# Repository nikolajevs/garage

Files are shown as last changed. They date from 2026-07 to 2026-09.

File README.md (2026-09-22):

# 🚨 Garage Alarm System — ESP32 + LD2410C + RC522

Умная охранная сигнализация для гаража на базе ESP32.

## Возможности

- Детекция присутствия человека с помощью радара **LD2410C** (mmWave)
- Управление через RFID-считыватель **RC522** (SPI)
- Задержки на выход (30 сек) и вход (15 сек)
- Фильтр ложных срабатываний: тревога, только если присутствие держится не меньше 1 сек
- Автоматическое отключение сирены через 3 минуты (LED продолжает мигать, пока охрану не снимут картой)
- **Динамическое добавление карт через мастер-карту** — не нужно перепрошивать, чтобы добавить новую карту
- Все карты и мастер-карта хранятся в NVS (переживают перезагрузку и перепрошивку)
- Состояние охраны тоже хранится в NVS — отключение питания не снимает охрану
- Контроль радара: если при охране от LD2410 нет данных дольше 3 сек (обрыв/саботаж), запускается тревога
- Автоматическая переинициализация RC522, если он завис или сбросился от помех

## Пины подключения

| Компонент | Пин ESP32 |
|---|---|
| LD2410C TX | GPIO16 (RX2)  |
| LD2410C RX | GPIO17 (TX2)  |
| RC522 SDA (SS)  | GPIO5 |
| RC522 RST | GPIO4 |
| RC522 SCK | GPIO18 |
| RC522 MOSI | GPIO23 |
| RC522 MISO | GPIO19 |
| RC522 3.3V | 3.3V (⚠️ не 5V!) |
| Сирена/Реле | GPIO32 |
| LED индикатор | GPIO2 |

⚠️ RC522 питается строго от 3.3V — модуль обычно не имеет своего стабилизатора и не 5V-толерантен.
Сирену пришлось перенести с GPIO18 на GPIO32, так как GPIO18 занят аппаратным SPI (SCK) для RC522.

## Как работает

- **DISARMED** — Охрана выключена
- **EXIT_DELAY** — 30 сек на выход (медленное мигание LED)
- **ARMED** — Охрана активна (LED горит)
- **ENTRY_DELAY** — 15 сек на отключение (быстрое мигание)
- **ALARM** — Тревога! Сирена орёт

## Настройка

1. Загрузите прошивку и откройте Serial Monitor (115200 baud).
2. При первом запуске мастер-карта ещё не назначена — поднесите **любую** карту к RC522, она автоматически станет мастер-картой и сохранится в NVS.
3. Чтобы добавить обычную карту: поднесите **мастер-карту** (система должна быть снята с охраны, DISARMED) — LED начнёт часто мигать, это значит включён режим добавления. В течение 15 секунд поднесите новую карту — она сохранится в список разрешённых.
4. Повторное поднесение мастер-карты выключает режим добавления вручную (иначе он сам выключится через 15 сек).
5. Откалибруйте LD2410C через приложение HLKRadarTool.

### Serial-команды

| Команда | Действие |
|---|---|
| `list` | Показать мастер-карту и список обычных карт |
| `clear` | Удалить все обычные карты (мастер-карта не трогается) |
| `resetmaster` | Сбросить мастер-карту — следующая поднесённая карта станет новой мастер-картой |

## Библиотеки

- [MyLD2410](https://github.com/iavorvel/MyLD2410)
- [MFRC522](https://github.com/miguelbalboa/rfid)

**Проект готов к использованию!**

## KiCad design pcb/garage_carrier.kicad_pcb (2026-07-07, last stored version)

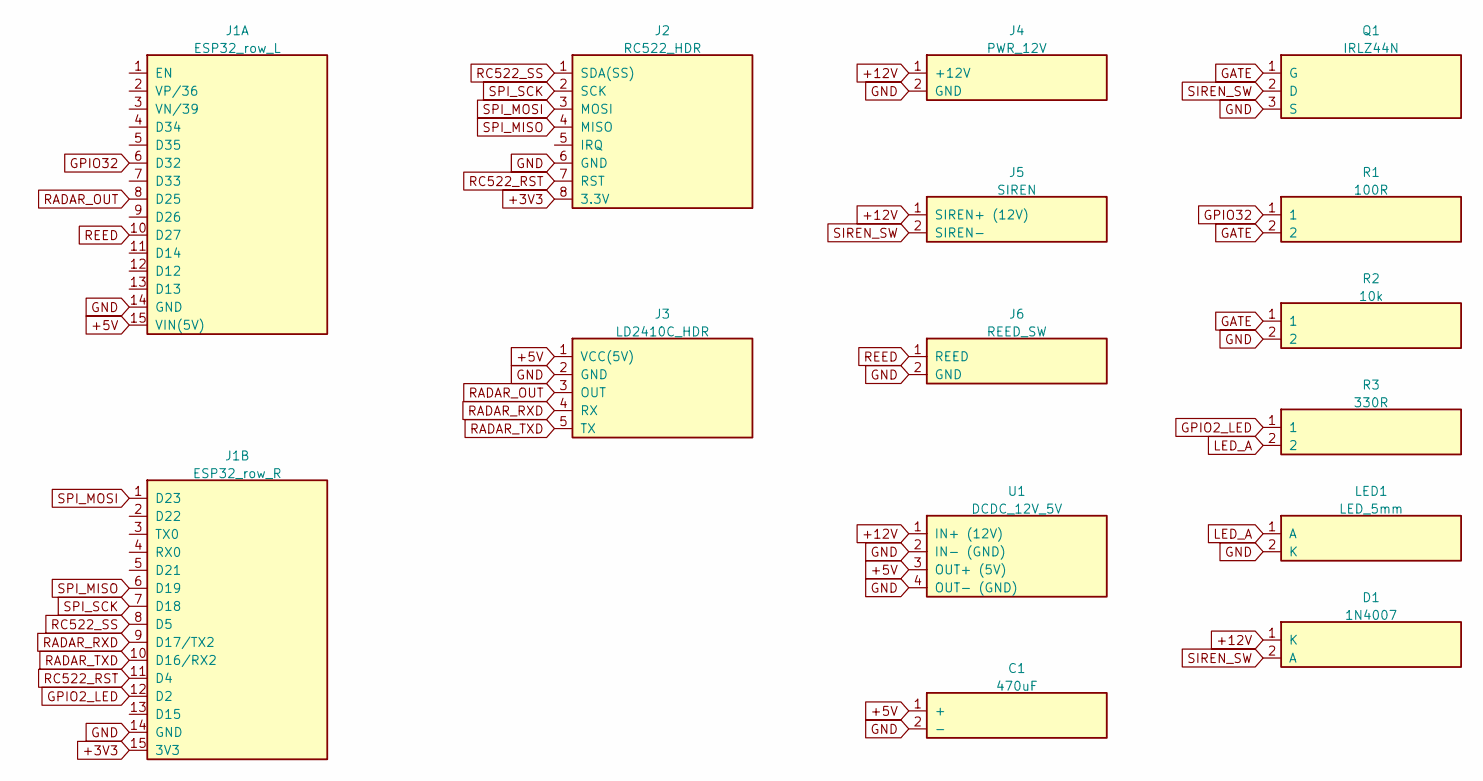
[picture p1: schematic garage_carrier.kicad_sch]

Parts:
C1: 470uF; C1
D1: 1N4007; D1
J1A: ESP32_row_L; J1A
J1B: ESP32_row_R; J1B
J2: RC522_HDR; J2
J3: LD2410C_HDR; J3
J4: PWR_12V; J4
J5: SIREN; J5
J6: REED_SW; J6
LED1: LED_5mm; LED1
Q1: IRLZ44N; Q1
R1: 100R; R1
R2: 10k; R2
R3: 330R; R3
U1: DCDC_12V_5V; U1

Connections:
+3V3: J1B.15 (3V3), J2.8 (3.3V)
+5V: C1.1 (+), J1A.15 (VIN(5V)), J3.1 (VCC(5V)), U1.3 (OUT+ (5V))
+12V: D1.1 (K), J4.1 (+12V), J5.1 (SIREN+ (12V)), U1.1 (IN+ (12V))
GATE: Q1.1 (G), R1.2, R2.1
GND: C1.2 (-), J1A.14 (GND), J1B.14 (GND), J2.6 (GND), J3.2 (GND), J4.2 (GND), J6.2 (GND), LED1.2 (K), Q1.3 (S), R2.2, U1.2 (IN- (GND)), U1.4 (OUT- (GND))
GPIO2_LED: J1B.12 (D2), R3.1
GPIO32: J1A.6 (D32), R1.1
LED_A: LED1.1 (A), R3.2
RADAR_OUT: J1A.8 (D25), J3.3 (OUT)
RADAR_RXD: J1B.9 (D17/TX2), J3.4 (RX)
RADAR_TXD: J1B.10 (D16/RX2), J3.5 (TX)
RC522_RST: J1B.11 (D4), J2.7 (RST)
RC522_SS: J1B.8 (D5), J2.1 (SDA(SS))
REED: J1A.10 (D27), J6.1 (REED)
SIREN_SW: D1.2 (A), J5.2 (SIREN-), Q1.2 (D)
SPI_MISO: J1B.6 (D19), J2.4 (MISO)
SPI_MOSI: J1B.1 (D23), J2.3 (MOSI)
SPI_SCK: J1B.7 (D18), J2.2 (SCK)

Board: 2 copper layers, 19 parts (0 on the bottom side), 18 nets, no tracks yet.

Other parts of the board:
H1: M3; H1
H2: M3; H2
H3: M3; H3
H4: M3; H4

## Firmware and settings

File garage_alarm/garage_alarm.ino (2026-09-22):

#include <Arduino.h>
#include <MyLD2410.h>
#include <SPI.h>
#include <MFRC522.h>
#include <Preferences.h>

// ================= ПИНЫ =================
#define LD2410_RX 16
#define LD2410_TX 17
#define RC522_SS   5
#define RC522_RST  4
// SPI (SCK/MOSI/MISO) - аппаратные пины ESP32: GPIO18/23/19
#define SIREN_PIN 32   // сирену перенесли с GPIO18, т.к. он занят под аппаратный SPI (SCK)
#define LED_PIN   2

// ================= НАСТРОЙКИ =================
const unsigned long EXIT_DELAY_MS   = 30000;
const unsigned long ENTRY_DELAY_MS  = 15000;
const unsigned long ALARM_TIMEOUT   = 180000;
const unsigned long MOTION_HOLD_MS  = 1000;
const unsigned long RFID_DEBOUNCE_MS = 600;
const unsigned long ADD_MODE_TIMEOUT_MS = 15000; // время на поднесение новой карты после мастер-карты
const unsigned long RADAR_TIMEOUT_MS = 3000;     // нет кадров от LD2410 дольше этого при охране = обрыв/саботаж
const unsigned long RC522_CHECK_MS   = 5000;     // период проверки, что RC522 жив
const int MAX_CARDS = 20;

// ================= СОСТОЯНИЯ =================
enum State { DISARMED, EXIT_DELAY, ARMED, ENTRY_DELAY, ALARM };
State state = DISARMED;
unsigned long stateTimer = 0;
unsigned long lastRFIDReadTime = 0;
unsigned long lastRC522Check = 0;

bool presence = false;             // по последнему кадру радара кто-то есть
unsigned long presenceSince = 0;   // когда присутствие началось
unsigned long lastRadarFrame = 0;  // когда пришёл последний кадр с данными

bool addModeActive = false;
unsigned long addModeStartedAt = 0;

// ================= УСТРОЙСТВА =================
MyLD2410 radar(Serial2);
MFRC522 rfid(RC522_SS, RC522_RST);
Preferences prefs;

// ================= ХРАНЕНИЕ КАРТ (NVS) =================
String masterUID = "";               // пусто = мастер-карта ещё не назначена
String storedCards[MAX_CARDS];
int storedCardCount = 0;
bool armedInNVS = false;             // была ли система на охране перед перезагрузкой

void loadFromNVS() {
  prefs.begin("garage", true);
  masterUID = prefs.getString("master", "");
  armedInNVS = prefs.getBool("armed", false);
  storedCardCount = prefs.getInt("count", 0);
  if (storedCardCount > MAX_CARDS) storedCardCount = MAX_CARDS;
  for (int i = 0; i < storedCardCount; i++) {
    storedCards[i] = prefs.getString(("card" + String(i)).c_str(), "");
  }
  prefs.end();
}

void saveMaster() {
  prefs.begin("garage", false);
  prefs.putString("master", masterUID);
  prefs.end();
}

void saveArmed(bool armed) {
  prefs.begin("garage", false);
  prefs.putBool("armed", armed);
  prefs.end();
}

void saveCards() {
  prefs.begin("garage", false);
  prefs.putInt("count", storedCardCount);
  for (int i = 0; i < storedCardCount; i++) {
    prefs.putString(("card" + String(i)).c_str(), storedCards[i]);
  }
  prefs.end();
}

bool isKnownCard(const String &uid) {
  for (int i = 0; i < storedCardCount; i++) {
    if (storedCards[i] == uid) return true;
  }
  return false;
}

bool addCard(const String &uid) {
  if (isKnownCard(uid)) return false;
  if (storedCardCount >= MAX_CARDS) return false;
  storedCards[storedCardCount++] = uid;
  saveCards();
  return true;
}

// ================= HELPERS =================
String uidToString(byte* uid, byte len) {
  String s = "";
  for (byte i = 0; i < len; i++) {
    if (uid[i] < 0x10) s += "0";
    s += String(uid[i], HEX);
  }
  s.toUpperCase();
  return s;
}

void blink(int times, int onMs, int offMs) {
  for (int i = 0; i < times; i++) {
    digitalWrite(LED_PIN, HIGH);
    delay(onMs);
    digitalWrite(LED_PIN, LOW);
    if (i < times - 1) delay(offMs);
  }
}

void sirenBeep(int ms) {
  digitalWrite(SIREN_PIN, HIGH);
  delay(ms);
  digitalWrite(SIREN_PIN, LOW);
}

void setState(State s) {
  bool wasArmed = (state != DISARMED);
  state = s;
  stateTimer = millis();
  Serial.printf("State -> %d\n", s);
  // запоминаем факт охраны в NVS, чтобы отключение питания не снимало охрану
  if ((s != DISARMED) != wasArmed) saveArmed(s != DISARMED);
  if (s == DISARMED) {
    digitalWrite(SIREN_PIN, LOW);
    digitalWrite(LED_PIN, LOW);
  }
}

// ================= SETUP =================
void setup() {
  Serial.begin(115200);
  Serial.setTimeout(50); // readStringUntil не будет висеть 1 сек, если в мониторе "No line ending"
  pinMode(SIREN_PIN, OUTPUT);
  pinMode(LED_PIN, OUTPUT);
  digitalWrite(SIREN_PIN, LOW);
  digitalWrite(LED_PIN, LOW);

  Serial2.setRxBufferSize(1024); // запас на время блокирующих blink()/sirenBeep()
  Serial2.begin(256000, SERIAL_8N1, LD2410_RX, LD2410_TX);
  if (!radar.begin()) {
    Serial.println("LD2410 не отвечает! Проверьте подключение.");
  }
  lastRadarFrame = millis();

  SPI.begin(); // SCK=18, MISO=19, MOSI=23 по умолчанию на ESP32
  rfid.PCD_Init();

  // не блокируем всю систему: радар и сирена работают, RC522 будет переинициализироваться в loop()
  byte version = rfid.PCD_ReadRegister(rfid.VersionReg);
  if (version == 0x00 || version == 0xFF) {
    Serial.println("RC522 not found! Повторная инициализация каждые 5 сек.");
  } else {
    Serial.print("RC522 OK, version 0x");
    Serial.println(version, HEX);
  }

  loadFromNVS();

  if (masterUID == "") {
    Serial.println("Мастер-карта не назначена! Поднесите любую карту к RC522 - она станет мастер-картой.");
  } else {
    Serial.println("Мастер-карта: " + masterUID);
  }
  Serial.println("Обычных карт в списке: " + String(storedCardCount));
  Serial.println("Serial-команды: list, clear, resetmaster");

  if (armedInNVS) {
    Serial.println("Перезагрузка во время охраны - снова на охране.");
    setState(ARMED);
  }
  Serial.println("Garage Alarm READY");
}

// ================= RC522 =================
// RC522 может зависнуть или сброситься от помех (например, от реле сирены):
// после сброса его регистры возвращаются к умолчанию и антенна выключена.
void checkRC522() {
  if (millis() - lastRC522Check < RC522_CHECK_MS) return;
  lastRC522Check = millis();

  byte version = rfid.PCD_ReadRegister(rfid.VersionReg);
  bool antennaOn = (rfid.PCD_ReadRegister(rfid.TxControlReg) & 0x03) == 0x03;
  if (version == 0x00 || version == 0xFF || !antennaOn) {
    Serial.println("RC522 не отвечает, переинициализация...");
    rfid.PCD_Init();
  }
}

// ================= RFID =================
void checkRFID() {
  if (millis() - lastRFIDReadTime < RFID_DEBOUNCE_MS) return;
  if (!rfid.PICC_IsNewCardPresent()) return;
  if (!rfid.PICC_ReadCardSerial()) return;

  String tag = uidToString(rfid.uid.uidByte, rfid.uid.size);
  lastRFIDReadTime = millis();
  Serial.println("TAG: " + tag);

  // --- Назначение мастер-карты при первом использовании ---
  if (masterUID == "") {
    if (isKnownCard(tag)) {
      // иначе обычная карта станет мастер-картой и перестанет ставить/снимать охрану
      Serial.println("Эта карта уже в списке обычных - поднесите другую (или сначала clear).");
      blink(2, 400, 200);
      rfid.PICC_HaltA();
      rfid.PCD_StopCrypto1();
      return;
    }
    masterUID = tag;
    saveMaster();
    Serial.println("Мастер-карта назначена: " + tag);
    blink(5, 100, 100);
    rfid.PICC_HaltA();
    rfid.PCD_StopCrypto1();
    return;
  }

  // --- Поднесли мастер-карту: переключаем режим добавления ---
  if (tag == masterUID) {
    if (state != DISARMED) {
      Serial.println("Режим добавления карт доступен только при снятой охране.");
      blink(2, 400, 200);
      rfid.PICC_HaltA();
      rfid.PCD_StopCrypto1();
      return;
    }
    addModeActive = !addModeActive;
    if (addModeActive) {
      addModeStartedAt = millis();
      Serial.println("Режим добавления ВКЛЮЧЁН. Поднесите новую карту в течение 15 сек.");
      blink(3, 150, 150);
    } else {
      Serial.println("Режим добавления выключен.");
      blink(1, 500, 0);
    }
    rfid.PICC_HaltA();
    rfid.PCD_StopCrypto1();
    return;
  }

  // --- Режим добавления активен: сохраняем новую карту ---
  if (addModeActive) {
    addModeActive = false;
    if (addCard(tag)) {
      Serial.println("Карта добавлена: " + tag);
      blink(3, 100, 100);
    } else {
      Serial.println("Карта уже есть в списке или лимит карт исчерпан: " + tag);
      blink(5, 80, 80);
    }
    rfid.PICC_HaltA();
    rfid.PCD_StopCrypto1();
    return;
  }

  // --- Обычная карта: ставим/снимаем с охраны ---
  if (isKnownCard(tag)) {
    if (state == DISARMED) {
      setState(EXIT_DELAY);
    } else {
      setState(DISARMED);
    }
    sirenBeep(150);
  } else {
    Serial.println("Access DENIED: " + tag);
    blink(1, 600, 0);
  }

  rfid.PICC_HaltA();
  rfid.PCD_StopCrypto1();
}

// ================= SERIAL КОМАНДЫ =================
void checkSerialCommands() {
  if (!Serial.available()) return;
  String cmd = Serial.readStringUntil('\n');
  cmd.trim();
  cmd.toLowerCase();

  if (cmd == "list") {
    Serial.println("Мастер-карта: " + (masterUID == "" ? "не назначена" : masterUID));
    Serial.println("Обычные карты (" + String(storedCardCount) + "):");
    for (int i = 0; i < storedCardCount; i++) {
      Serial.println("  " + storedCards[i]);
    }
  } else if (cmd == "clear") {
    storedCardCount = 0;
    saveCards();
    Serial.println("Список обычных карт очищен (мастер-карта сохранена).");
  } else if (cmd == "resetmaster") {
    masterUID = "";
    saveMaster();
    Serial.println("Мастер-карта сброшена. Поднесите новую карту, чтобы назначить её мастер-картой.");
  } else if (cmd.length() > 0) {
    Serial.println("Команды: list, clear, resetmaster");
  }
}

// ================= LOOP =================
void loop() {
  checkSerialCommands();
  checkRC522();
  checkRFID();

  // автоматический выход из режима добавления по таймауту
  if (addModeActive && millis() - addModeStartedAt > ADD_MODE_TIMEOUT_MS) {
    addModeActive = false;
    Serial.println("Время на добавление карты истекло, режим добавления выключен.");
  }

  // вычитываем все накопившиеся кадры радара
  MyLD2410::Response r;
  while ((r = radar.check()) != MyLD2410::FAIL) {
    if (r != MyLD2410::DATA) continue;
    lastRadarFrame = millis();
    bool p = radar.presenceDetected(); // движущаяся или неподвижная цель
    if (p && !presence) presenceSince = millis();
    presence = p;
  }

  unsigned long now = millis();

  // индикация режима добавления имеет приоритет над обычной индикацией LED
  if (addModeActive) {
    digitalWrite(LED_PIN, (now / 200) % 2);
  } else {
    switch (state) {
      case DISARMED:
        digitalWrite(LED_PIN, LOW);
        break;
      case EXIT_DELAY:
        digitalWrite(LED_PIN, (now / 300) % 2);
        if (now - stateTimer > EXIT_DELAY_MS) setState(ARMED);
        break;
      case ARMED:
        digitalWrite(LED_PIN, HIGH);
        // тревога, только если присутствие держится не меньше MOTION_HOLD_MS
        if (presence && now - presenceSince >= MOTION_HOLD_MS) {
          setState(ENTRY_DELAY);
        } else if (now - lastRadarFrame > RADAR_TIMEOUT_MS) {
          Serial.println("Нет данных от LD2410 - обрыв или саботаж!");
          setState(ENTRY_DELAY);
        }
        break;
      case ENTRY_DELAY:
        digitalWrite(LED_PIN, (now / 150) % 2);
        if (now - stateTimer > ENTRY_DELAY_MS) setState(ALARM);
        break;
      case ALARM:
        // сирена звучит ALARM_TIMEOUT, потом молчит; LED мигает, пока охрану не снимут картой
        digitalWrite(SIREN_PIN, now - stateTimer < ALARM_TIMEOUT ? HIGH : LOW);
        digitalWrite(LED_PIN, (now / 80) % 2);
        break;
    }
  }

  delay(10);
}

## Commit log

2026-07-06 Add final garage alarm sketch ESP32 + LD2410C + PN532
2026-07-07 Заменить PN532 на RC522 (SPI): обновлены пины и README
2026-07-07 Динамическое добавление карт через мастер-карту (хранение в NVS)
2026-07-07 Добавить KiCad проект несущей платы (схема, плата, генератор, BOM)
    [garage_carrier.kicad_pcb, garage_carrier.kicad_sch]
2026-07-07 JLCPCB: правила проектирования в проекте, скрипт экспорта гербер-файлов, инструкция по заказу
2026-07-07 Исправить экспорт для JLCPCB: отключить X2-формат гербер-файлов (--no-x2)
2026-09-22 Исправить баги сигнализации: компиляция, срабатывание тревоги, сирена, питание
    - Использовать реальный API MyLD2410 (check/presenceDetected) — скетч не компилировался
    - Фильтр присутствия: считать время от начала присутствия (раньше тревога не срабатывала никогда)
    - Сирена после ALARM_TIMEOUT выключается, а не дёргается каждый цикл
    - Хранить состояние охраны в NVS — отключение питания больше не снимает о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
    [garage_alarm.ino]
